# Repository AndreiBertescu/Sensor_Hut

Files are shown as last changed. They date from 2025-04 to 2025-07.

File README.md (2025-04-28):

# SensorHut V2

<p align="center"><br>
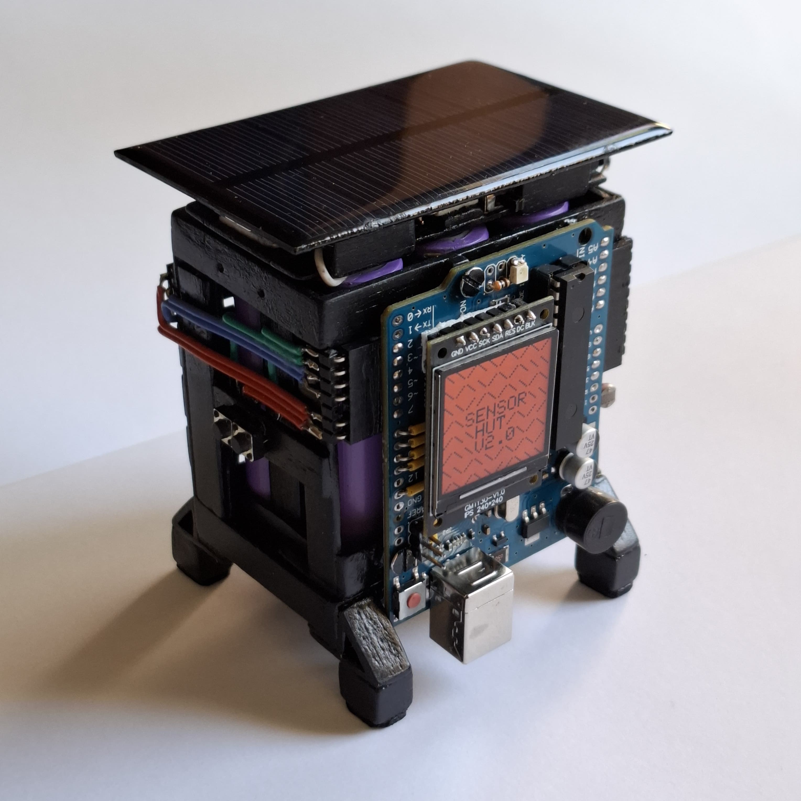
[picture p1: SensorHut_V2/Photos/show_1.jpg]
render
  
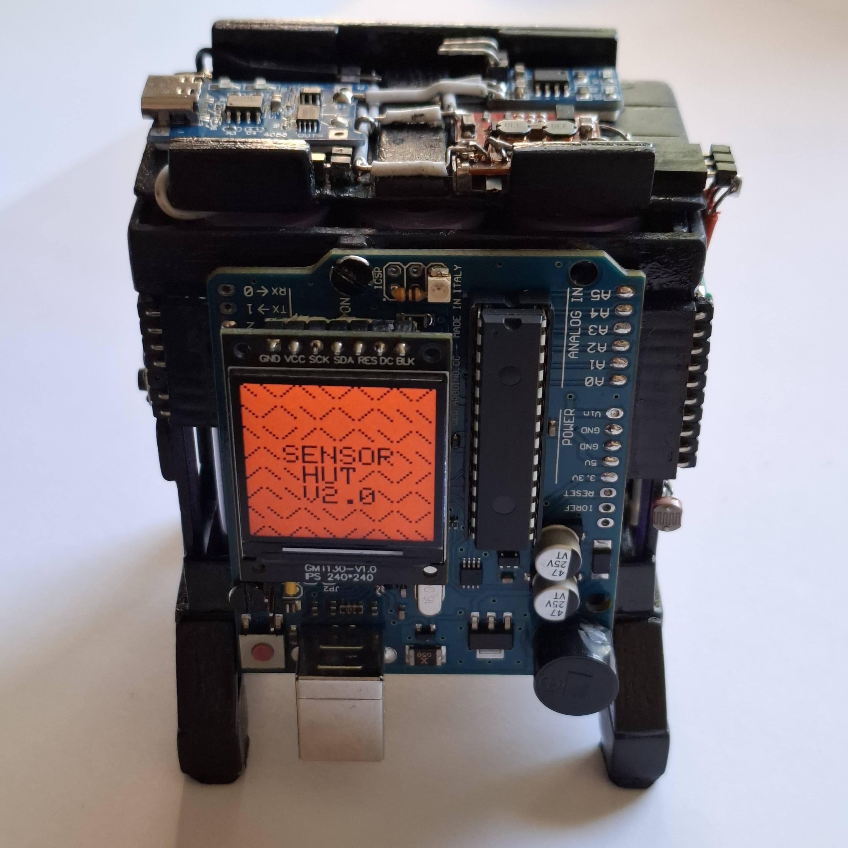
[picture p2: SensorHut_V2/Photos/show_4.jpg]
  
</p>

## Description
- The SensorHut is an Arduino-powered sensor array that can measure temperature, humidity, barometric pressure, light level, along with time-keeping and battery voltage measurement. It has a 2.4" LCD display that shows all this data, two push buttons, and a 6-cell rechargeable battery pack that can keep it powered for up to 2 weeks.

### Features
- **All the sensors are removable**, along with the battery pack, Arduino, and power circuit, allowing for easy maintenance, replacement, or reuse of components.
- It is powered by six 2200mAh LiPo batteries that can be recharged through USB-C or an attachable solar panel.
- The power consumption is 145mW while in sleep mode and 925mW while the screen is lit. Given the battery capacity and assuming no solar charging, the device should last about 15 days.
- It features two push buttons:
  - The first button refreshes sensor data and turns on the display for the programmed 16 seconds.
  - The second button toggles **power-saving mode**, which disables the LED, buzzer, and display backlight for a longer duration (10 minutes for power-saving mode, 1 minute for standard mode).
- The main Arduino board has been heavily modified to decrease power consumption and ease assembly:
  - All female pin sockets were removed and reattached on the underside of the board.
  - Since the required 5V is generated with an external step-up converter, the 12V power connector was replaced with a buzzer.
  - An LED and the 1.3" LCD display were wired and attached directly to the Arduino board, reducing the number of placed components and making them visible.
  - Always-on and auxiliary LEDs were removed.
  - The power pins on the ATMEGA16U2 auxiliary IC, along with the RX and TX LEDs, were rewired to be active only when the board is connected via the USB-B port ([tutorial](https://www.defproc.co.uk/tutorial/how-to-reduce-arduino-uno-power-usage-by-95/)).

<p align="center"><br>
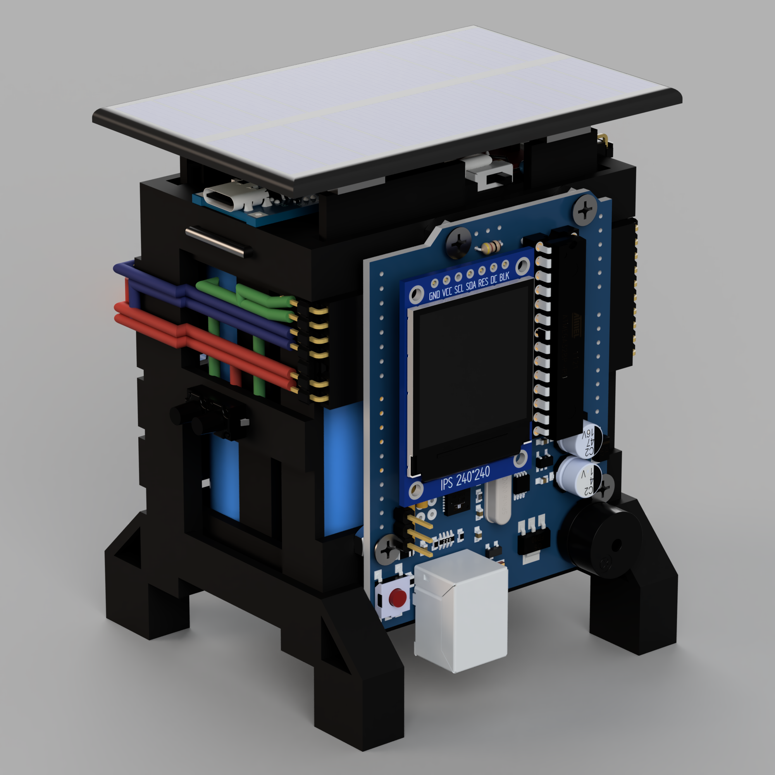
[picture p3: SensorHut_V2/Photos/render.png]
  
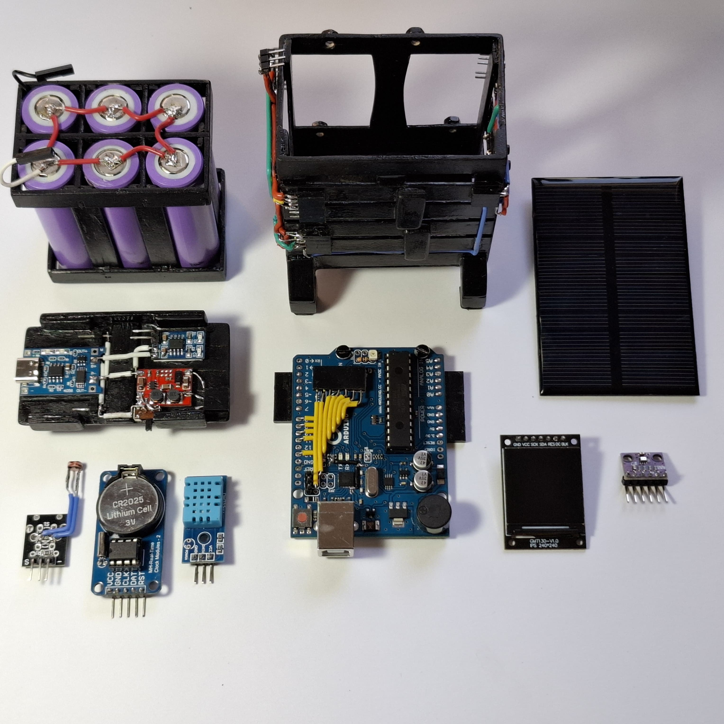
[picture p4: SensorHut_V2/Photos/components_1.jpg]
  
  <br>
  gif
</p>

## Improvements Added in Version 2
- Version 2's frame was built from popsicle sticks attached with Loctite superglue, offering a much stronger structure compared to Version 1's 1mm steel wireframe.
- Five more batteries were added to greatly increase battery capacity.
- Greater attention was given to frame design. The whole SensorHut was designed in tandem in Fusion 360 to ensure proper sizing and simplify assembly.
- The Arduino board is now much more visible and plays a bigger role in the overall aesthetics of the SensorHut.
- The power delivery circuits were removed from the solar panel and placed on a dedicated frame on top of the hut.
- The SensorHut can now function entirely without the solar panel (in Version 1, the solar charging was very weak).
- The wire harness was greatly simplified from the previous "spiderweb" mess. Wires are now routed neatly along the left and right sides of the hut and can easily be removed by detaching the right-angle pin headers from the Arduino sockets.

## Bill of Materials
- Arduino Uno Rev3 - [www.arduino.cc](https://store.arduino.cc/en-ro/products/arduino-uno-rev3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)
- DHT11 module - [www.optimusdigital.ro](https://www.optimusdigital.ro/en/temperature-sensors/4762-modul-senzor-de-temperatura-dht11-cu-led.html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)
- BMP280 module - [www.optimusdigital.ro](https://www.optimusdigital.ro/en/pressure-sensors/12417-modul-senzor-de-presiune-barometric-bmp280.html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)
- KY-018 module - [www.optimusdigital.ro](https://www.optimusdigital.ro/en/optical-sensors/13060-photosensitive-resistor-sensor-module-for-arduino.html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)
- DS1302 module - [www.optimusdigital.ro](https://www.optimusdigital.ro/en/all-products/12988-ds1302-real-time-clock-module-no-battery.html)
- ST7789 TFT LCD - [www.aliexpress.com](https://www.aliexpress.com/item/1005008175467166.html)
- 2x push buttons - [www.optimusdigital.ro](https://www.optimusdigital.ro/en/buttons-and-switches/1119-6x6x6-push-button.html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)
- Passive buzzer - [www.optimusdigital.ro](https://www.optimusdigital.ro/en/buzzers/634-5v-passive-buzzer.html?search_query=buzzer&results=87)
- Single-strand wires - [www.optimusdigital.ro](https://www.optimusdigital.ro/en/kits/11951-plusivo-pvc-insulated-wire-kit-20awg-6-colors-7m-each.html)
- 5.5V 120mA polycrystalline solar cell - [www.aliexpress.com](https://www.aliexpress.com/item/1005007402518746.html)
- 1A 5V for 3.7V solar controller - [www.aliexpress.com](https://www.aliexpress.com/item/1005003063466363.html)
- 2.5–15V to 5V step-up voltage regulator - [www.aliexpress.com](https://www.aliexpress.com/item/1005005911490910.html)
- 5V 1A USB-C lithium battery charger - [www.aliexpress.com](https://www.aliexpress.com/item/1005003598600322.html)
- 6x 3.7V 2200mAh rechargeable batteries - [www.aliexpress.com](https://www.aliexpress.com/item/1005001265547747.html)
- 2.54mm pitch pin headers and sockets of various lengths - [www.optimusdigital.ro](https://www.optimusdigital.ro/en/kits/4737-connector-assortment-kit-1004-pcs.html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)
- 1MΩ resistor
- 330Ω resistor
- Green SMD LED
- SPDT switch
- 30x1mm steel wires (for 2x clamps)
- Popsicle sticks (for the frame)

## Version 1 Schematic
(Note: Version 2 has a different pinout.)
Schematic1

## Version 1 Images
Bare frame with all detachable components removed

<p align="center">
  Bare Frame 1
  Bare Frame 2
</p>

Components

<p align="center">
  Components 1
  Components 2
</p>

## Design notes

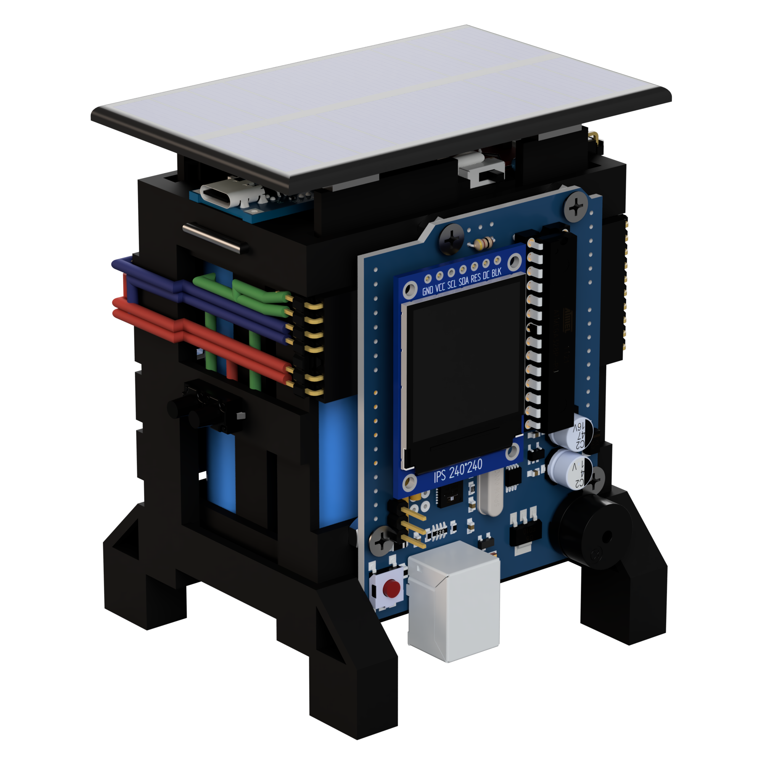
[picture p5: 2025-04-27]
SensorHut_V2/Photos/render_no_background.png

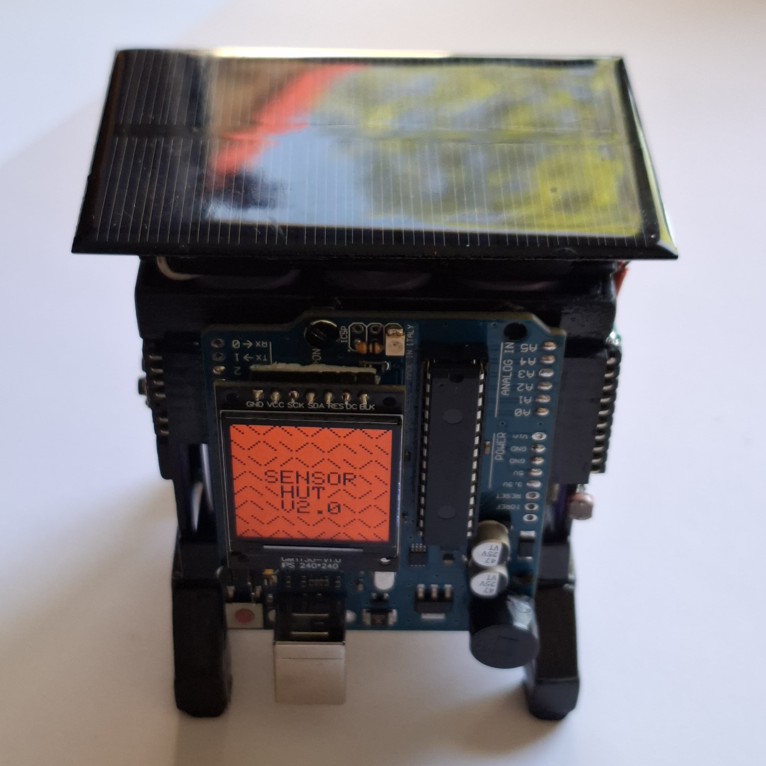
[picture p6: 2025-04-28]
SensorHut_V2/Photos/show_3.jpg

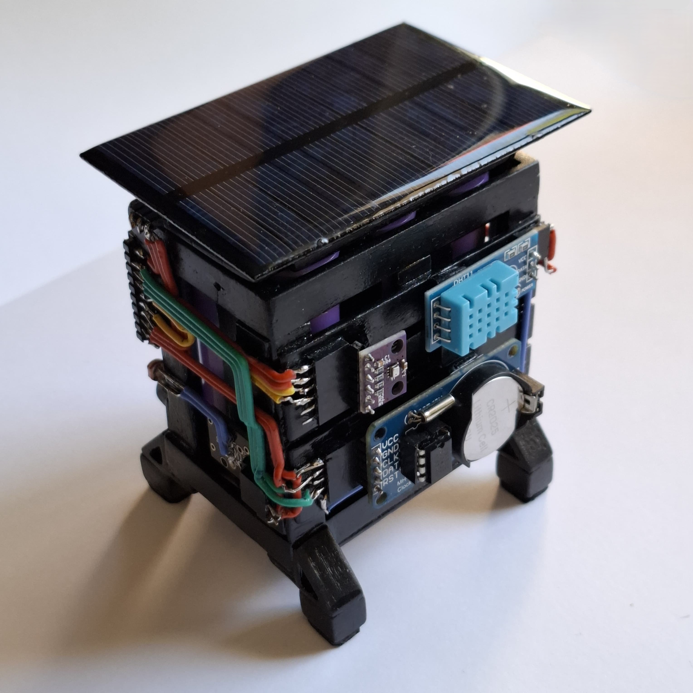
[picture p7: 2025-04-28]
SensorHut_V2/Photos/show_2.jpg

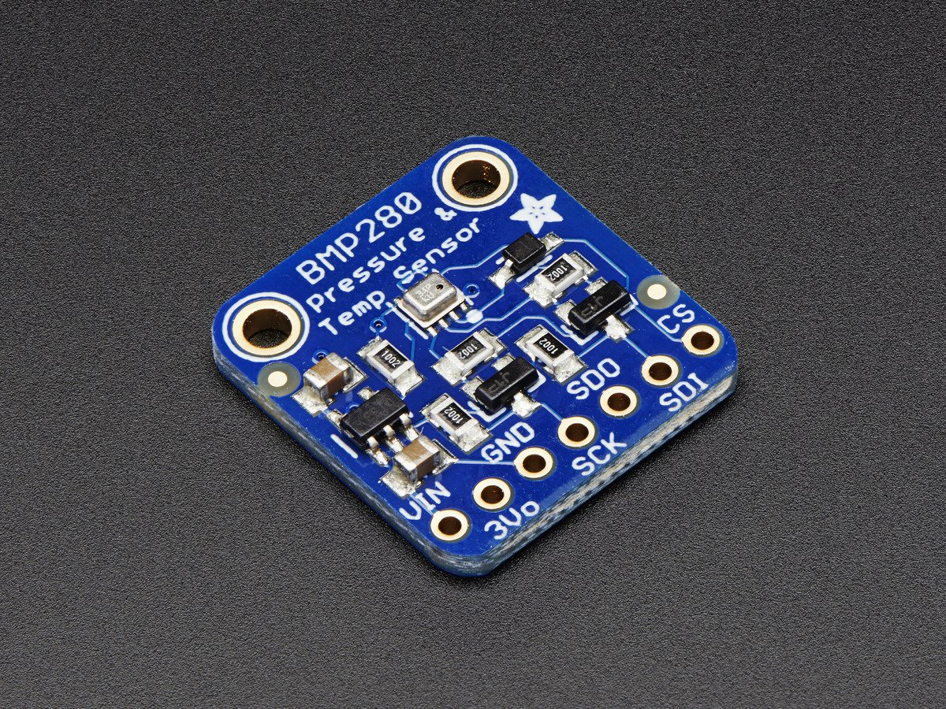
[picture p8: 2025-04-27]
SensorHut_V2/src/bmp280/assets/board.jpg

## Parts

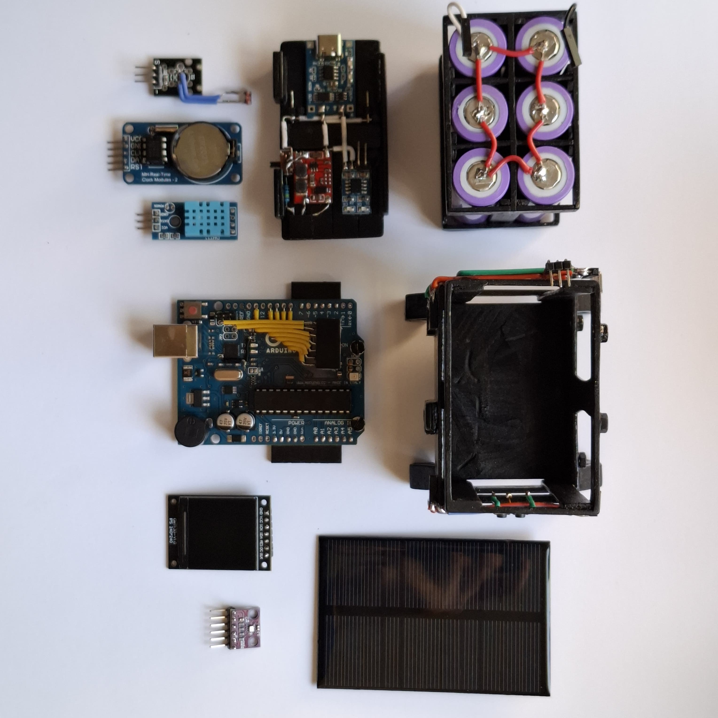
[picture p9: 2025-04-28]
SensorHut_V2/Photos/components_2.jpg

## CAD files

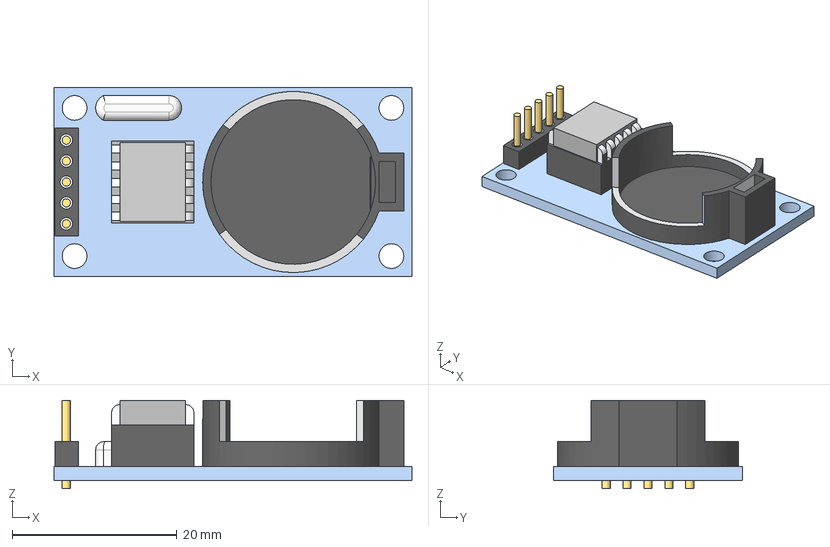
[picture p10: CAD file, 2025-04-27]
SensorHut_V2/3D models/Used parts/DS1302.stp
43.5 x 23.0 x 10.7 mm

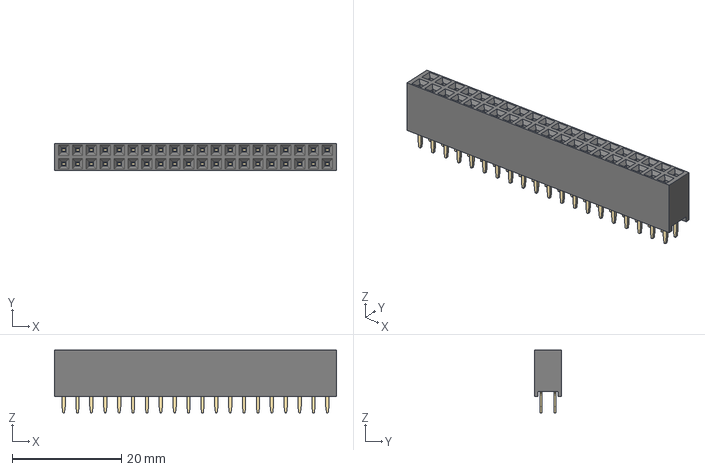
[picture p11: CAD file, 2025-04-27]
SensorHut_V2/3D models/Used parts/Header connectors/female/DS1023-2x20SF11.stp
51.6 x 5.00 x 11.5 mm

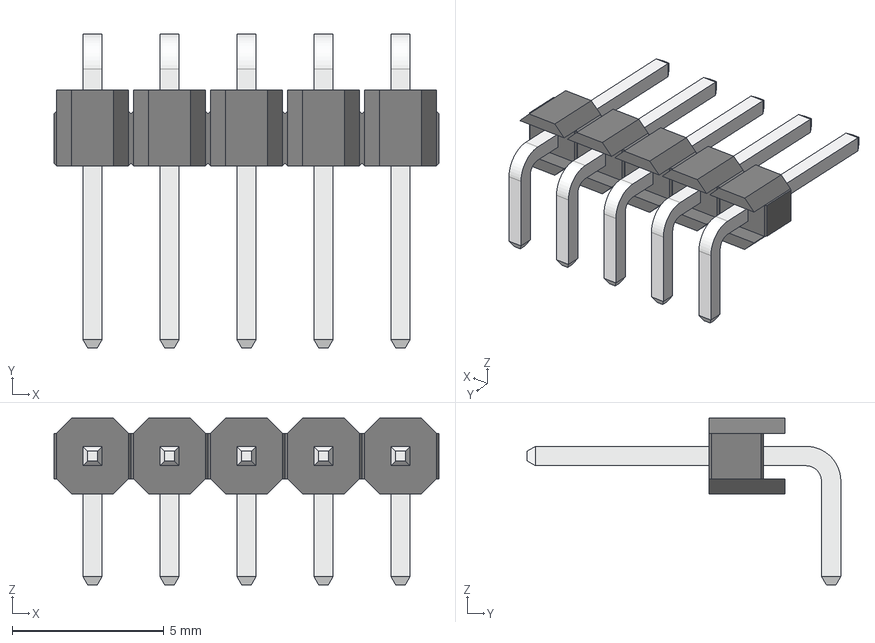
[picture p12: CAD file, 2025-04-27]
SensorHut_V2/3D models/Used parts/Header connectors/right_angle/2.54mm/DS1022-1x5RD61.stp
12.7 x 10.4 x 5.50 mm

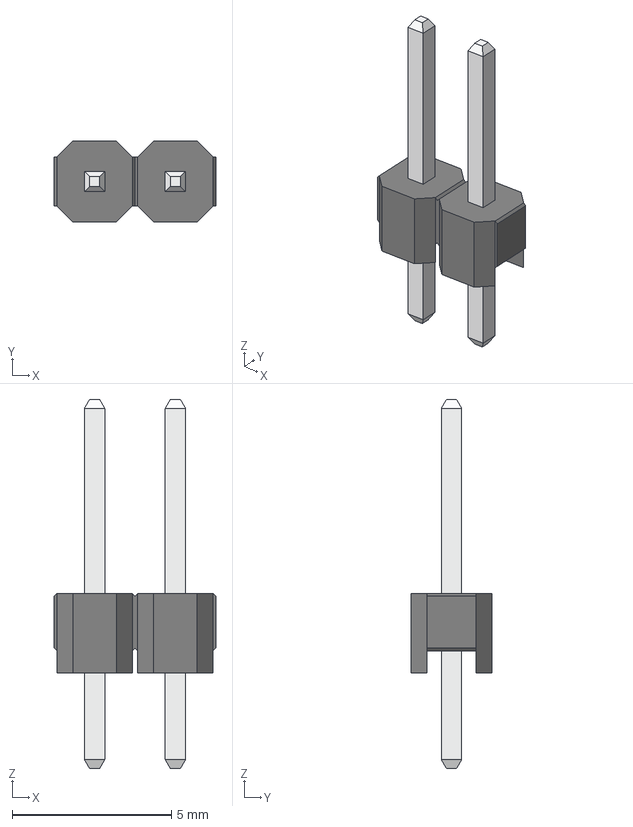
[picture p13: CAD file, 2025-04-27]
SensorHut_V2/3D models/Used parts/Header connectors/vertical/2.54mm/DS1021-1x2S61.stp
5.08 x 2.54 x 11.6 mm

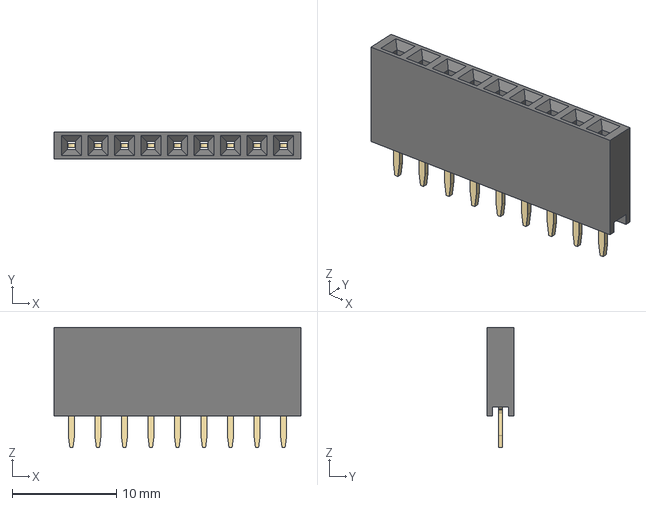
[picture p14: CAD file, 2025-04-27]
SensorHut_V2/3D models/Used parts/Header connectors/female/DS1023-1x9SF11.stp
23.7 x 2.54 x 11.5 mm

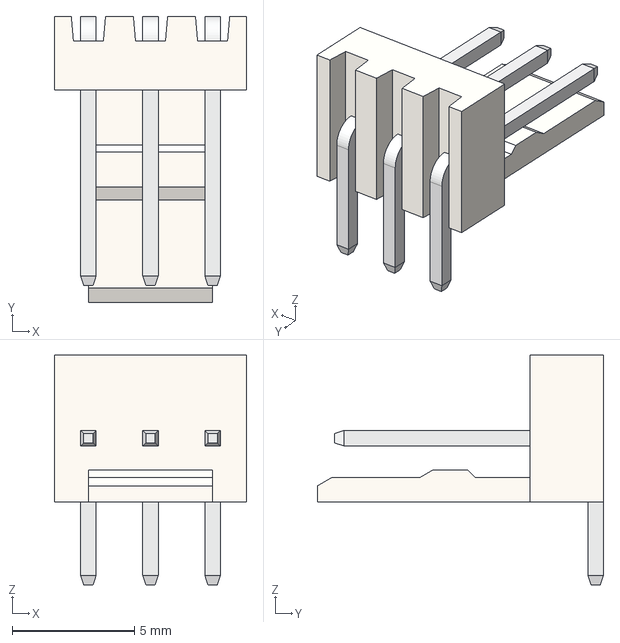
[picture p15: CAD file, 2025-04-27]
SensorHut_V2/3D models/Used parts/Header connectors/right_angle/2.54mm/DS1070-3MRV6B.stp
7.87 x 11.7 x 9.40 mm

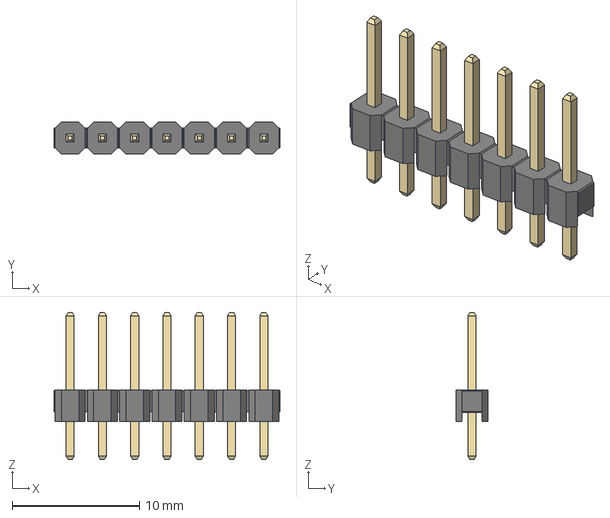
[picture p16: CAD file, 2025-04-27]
SensorHut_V2/3D models/Used parts/Header connectors/vertical/2.54mm/DS1021-1x7SF11.stp
17.8 x 2.54 x 11.6 mm

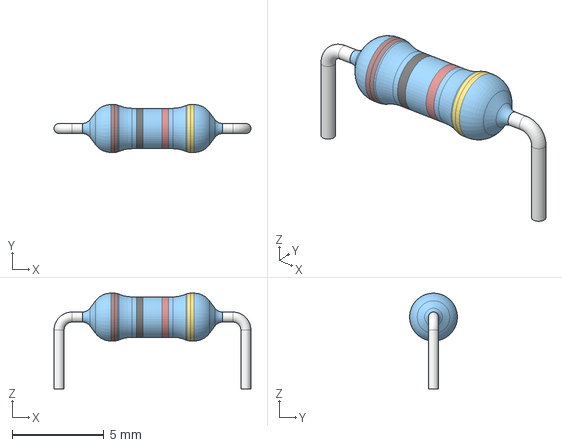
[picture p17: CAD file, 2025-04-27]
SensorHut_V2/3D models/Used parts/RES-0.25W-H-MF.stp
10.7 x 2.60 x 5.20 mm

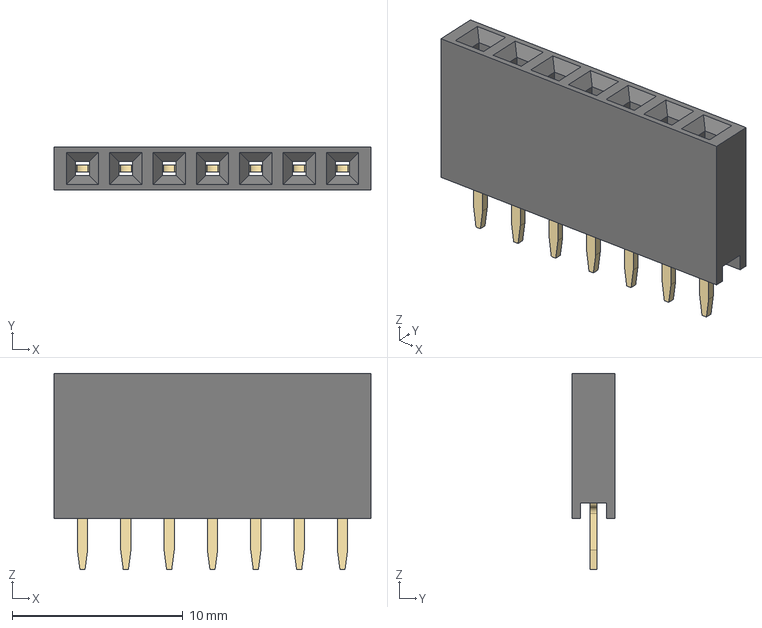
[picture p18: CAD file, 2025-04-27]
SensorHut_V2/3D models/Used parts/Header connectors/female/DS1023-1x7SF11.stp
18.6 x 2.54 x 11.5 mm

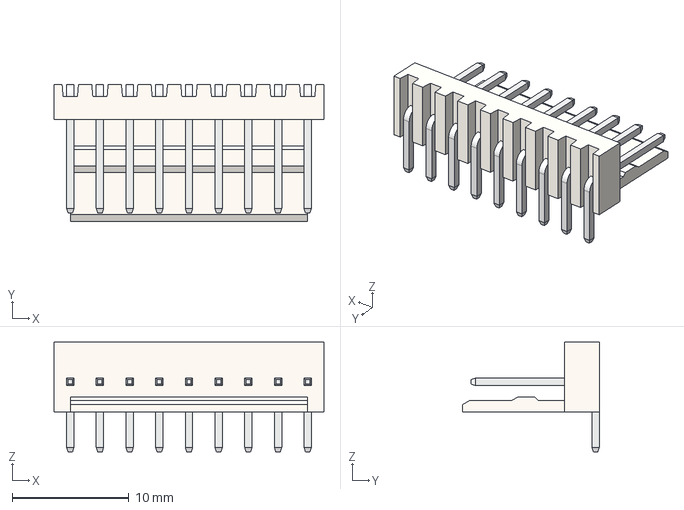
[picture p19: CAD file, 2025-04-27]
SensorHut_V2/3D models/Used parts/Header connectors/right_angle/2.54mm/DS1070-9MRV6B.stp
23.1 x 11.7 x 9.40 mm

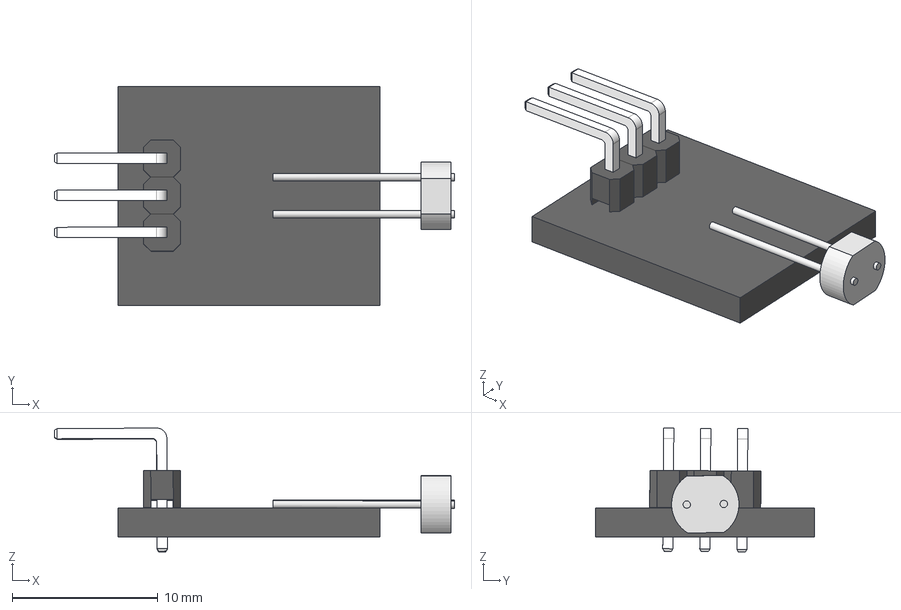
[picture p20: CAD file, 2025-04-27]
SensorHut_V2/3D models/Used parts/Photoresistor.stp
27.4 x 15.0 x 8.49 mm
board
User Library-PLS-3R
User Library-Photoresistor

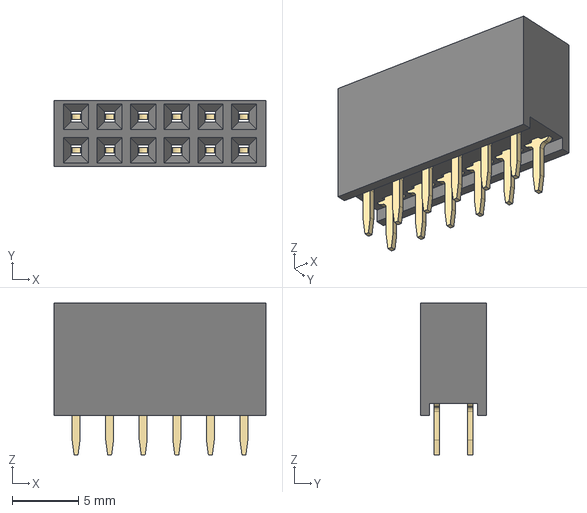
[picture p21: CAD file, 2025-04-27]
SensorHut_V2/3D models/Used parts/Header connectors/female/DS1023-2x6SF11.stp
16.0 x 5.00 x 11.5 mm

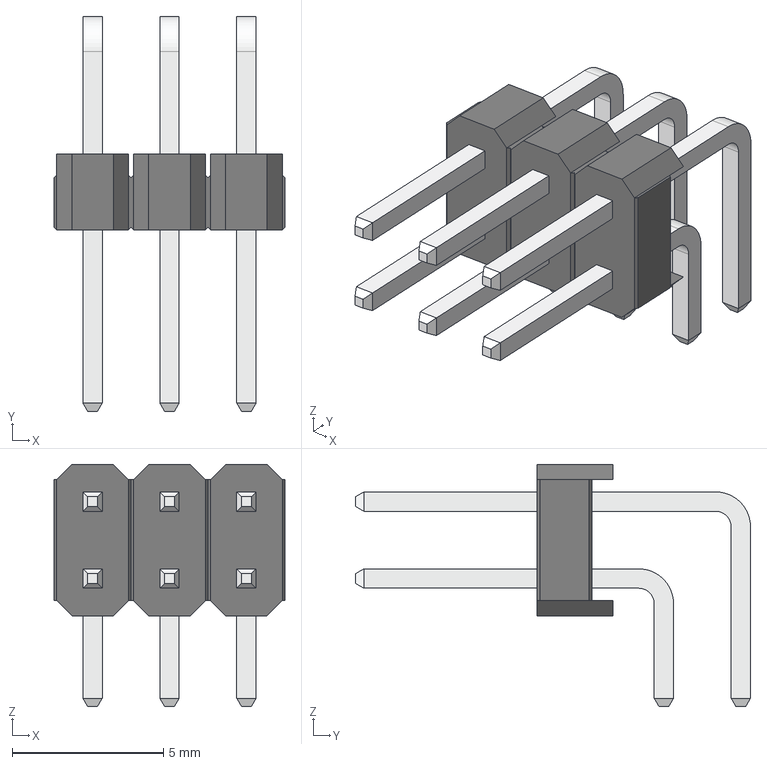
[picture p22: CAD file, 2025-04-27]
SensorHut_V2/3D models/Used parts/Header connectors/right_angle/2.54mm/DS1022-2x3R61.stp
7.62 x 13.0 x 8.00 mm

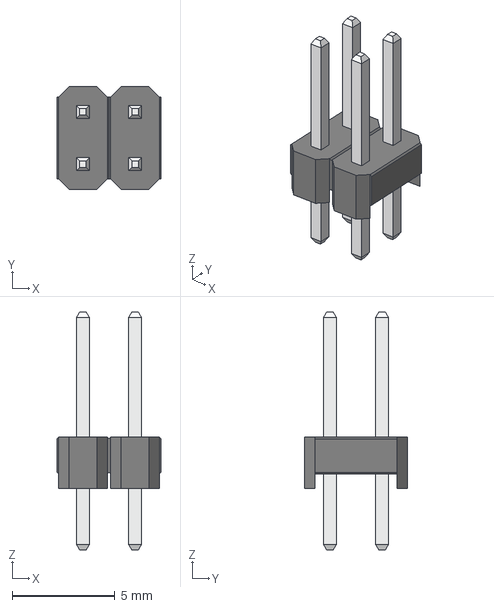
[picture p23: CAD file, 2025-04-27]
SensorHut_V2/3D models/Used parts/Header connectors/vertical/2.54mm/DS1021-2x2S61.stp
5.08 x 5.00 x 11.6 mm

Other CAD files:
SensorHut_V2/3D models/Used parts/Header connectors/vertical/2.54mm/DS1021-1x7S61.stp
SensorHut_V2/3D models/Used parts/OKY3501-5 Voltage Regulator.step
SensorHut_V2/3D models/Used parts/DHT11.step
SensorHut_V2/3D models/Used parts/Header connectors/female/DS1023-2x4SF11.stp
SensorHut_V2/3D models/Used parts/18650 Cell.stp
SensorHut_V2/3D models/Used parts/BMP280.stp
SensorHut_V2/3D models/Used parts/Buzzer.stp
SensorHut_V2/3D models/Used parts/Header connectors/female/DS1023-1x10SF11.stp
SensorHut_V2/3D models/Used parts/Header connectors/female/DS1023-1x1SF11.stp
SensorHut_V2/3D models/Used parts/Header connectors/female/DS1023-1x2SF11.stp
SensorHut_V2/3D models/Used parts/Header connectors/female/DS1023-1x3SF11.stp
SensorHut_V2/3D models/Used parts/Header connectors/female/DS1023-1x4SF11.stp
SensorHut_V2/3D models/Used parts/Header connectors/female/DS1023-1x5SF11.stp
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

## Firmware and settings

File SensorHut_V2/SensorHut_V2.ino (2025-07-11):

#include "src/dht11/dht11.h"
#include "src/ds1302/DS1302.h"
#include "src/bmp280/Adafruit_BMP280.h"
#include "src/st7789/Adafruit_ST7789.h"
#include <avr/sleep.h>
#include <avr/power.h>

#define ENABLE_SERIAL false
#define TIME_ALIVE 16000            // Rounds up to multiples of 4000
#define TIME_SHORT_SLEEP 60000 * 10 // Rounds up to multiples of 4000
#define TIME_LONG_SLEEP 60000 * 10  // Rounds up to multiples of 4000

#define DHT_PIN 4
#define LIGHT_SNSR_PIN A0  // Must be analog pin
#define BUZZER_PIN 6       // Must be 6 to use Timer #0 - HW constraint
#define BTN_1 2
#define BTN_2 3
#define LED_PIN 7          // HW constraint
#define RTC_RST_PIN 5      // Shouldn't be analog ???
#define RTC_DATA_PIN A2
#define RTC_SCKL_PIN A1
#define BMP280_SDA_PIN A4  // Must be sda pin
#define BMP280_SCL_PIN A5  // Must be scl pin
#define LCD_DC 9           // HW constraint
#define LCD_RST 10         // HW constraint
#define LCD_BRT 8          // HW constraint
#define LCD_SCK 13         // Must be sck pin - HW constraint
#define LCD_MOSI 11        // Must be mosi pin - HW constraint
#define BATT_SNSR_PIN A3   // Must be analog pin

// DHT11 temperature and humidity sensor
dht11 dht_inst;
uint8_t dht_temp;
uint8_t dht_hum;

// Battery sensor
int batt_snsr_val;

// Photoresistor
uint16_t light_snsr_val;

// Button interrupt flags
volatile bool btn_1_pressed;
volatile bool btn_2_pressed;

// DS1302 real time clock
DS1302 ds1302_inst(RTC_RST_PIN, RTC_DATA_PIN, RTC_SCKL_PIN);
Time t(2099, 1, 1, 0, 0, 0, Time::kSunday);

// BMP280 temperature, pressure and altitude sensor
Adafruit_BMP280 bmp;
int bmp_status;
int bmp_temp;
int bmp_press;
int bmp_altitude;

// ST7789 240x240 IPS display
Adafruit_ST7789 lcd = Adafruit_ST7789(-1, LCD_DC, LCD_RST);

// Other
char buf[64];
int power_saving_mode = 0;

void setup() {
  // Pin initialization
  pinMode(LIGHT_SNSR_PIN, INPUT);
  pinMode(BATT_SNSR_PIN, INPUT);
  pinMode(BUZZER_PIN, OUTPUT);
  pinMode(LED_PIN, OUTPUT);
  pinMode(LCD_BRT, OUTPUT);
  pinMode(BTN_1, INPUT_PULLUP);
  pinMode(BTN_2, INPUT_PULLUP);
  attachInterrupt(digitalPinToInterrupt(BTN_1), button1ISR, FALLING);
  attachInterrupt(digitalPinToInterrupt(BTN_2), button2ISR, FALLING);
  
  ACSR |= (1 << ACD);      // Disable analog comparator
  ADCSRA &= ~(1 << ADEN);  // Disable ADC
  TCCR1A = 0; // Disable Timer1
  TCCR1B = 0;
  TIMSK1 = 0;
  TCCR2A = 0; // Disable Timer2
  TCCR2B = 0;
  TIMSK2 = 0;

  // DS1302 initialization
  ds1302_inst.writeProtect(true);
  ds1302_inst.halt(false);
  t = ds1302_inst.time();
  if (t.getUnixFromMacros(__DATE__, __TIME__) > t.getUnixTime()) {
    ds1302_inst.writeProtect(false);
    ds1302_inst.time(Time(__DATE__, __TIME__));
    ds1302_inst.writeProtect(true);
  }

  // BMP280 initialization
  bmp_status = bmp.begin(BMP280_ADDRESS_ALT, BMP280_CHIPID);
  if (bmp_status) {
    bmp.setSampling(Adafruit_BMP280::MODE_NORMAL,     /* Operating Mode. */
                    Adafruit_BMP280::SAMPLING_X2,     /* Temp. oversampling */
                    Adafruit_BMP280::SAMPLING_X2,     /* Pressure oversampling */
                    Adafruit_BMP280::FILTER_X16,      /* Filtering. */
                    Adafruit_BMP280::STANDBY_MS_500); /* Standby time. */
  }

  // LCD initialization
  pinMode(LCD_BRT, OUTPUT);
  digitalWrite(LCD_BRT, HIGH);
  lcd.init(240, 240, SPI_MODE2);
  lcd.setRotation(2);
  lcd.setTextWrap(false);

  if (ENABLE_SERIAL) {
    // Serial initialization
    Serial.begin(9600);
  } else {
    // Buzzer confirm end of setup
    startupRoutine();
  }
}

void loop() {
  if (ENABLE_SERIAL) {
    Serial.println();
  }

  if(power_saving_mode != 2 || (btn_1_pressed || btn_2_pressed))
    digitalWrite(LCD_BRT, HIGH);

  handleButtons();
  handleBATT_SNSR();
  handleLIGHT_SNSR();
  handleDHT();
  handleBMP280();
  handleDS1302();
  handleLCD();

  sleepFor(TIME_ALIVE);
  digitalWrite(LCD_BRT, LOW);
  digitalWrite(LED_PIN, LOW);

  sleepFor(power_saving_mode == 1 ? TIME_LONG_SLEEP : TIME_SHORT_SLEEP);  // ~11mA less power usage than delay function
  // delay(1000);
}

void handleButtons() {
  if (btn_1_pressed) {
    activateBuzzer(1);
    power_saving_mode = (power_saving_mode + 1) % 3;

    btn_1_pressed = false;
  }
  if (btn_2_pressed) {
    if (power_saving_mode == 0) {
      activateBuzzer(2);
    } else {
      delay(500);
    }

    btn_2_pressed = false;
  }

  if (power_saving_mode == 0) {
    digitalWrite(LED_PIN, HIGH);
  }
}

void handleBATT_SNSR() {
  int battery_voltage = 0;
  int nr_samples = 20;

  ADCSRA |= (1 << ADEN);  // Enable ADC
  for(int i=0; i<nr_samples; i++) {
    battery_voltage += analogRead(BATT_SNSR_PIN);
    delay(10);
  }
  batt_snsr_val = map(battery_voltage/nr_samples, 0, 1023, 0, 500);
  ADCSRA &= ~(1 << ADEN);  // Disable ADC

  if (ENABLE_SERIAL) {
    sprintf(buf, "Battery sensor: %u.%.2uV", batt_snsr_val / 100 % 10, batt_snsr_val % 100);
    Serial.println(buf);
  }
}

void handleLIGHT_SNSR() {
  ADCSRA |= (1 << ADEN);  // Enable ADC
  light_snsr_val = map(analogRead(LIGHT_SNSR_PIN), 1023, 0, 0, 100);
  ADCSRA &= ~(1 << ADEN);  // Disable ADC

  if (ENABLE_SERIAL) {
    sprintf(buf, "Light sensor: %u%%", light_snsr_val);
    Serial.println(buf);
  }
}

void handleDHT() {
  int status = dht_inst.read(DHT_PIN);

  if (status == 0) {
    dht_temp = dht_inst.temperature;
    dht_hum = dht_inst.humidity;
  }

  if (ENABLE_SERIAL) {
    sprintf(buf, "DHT11:%d - T: %uC - H: %u%%", status, dht_temp, dht_hum);
    Serial.println(buf);
  }
}

void handleBMP280() {
  if (bmp_status != BMP280_CHIPID) {
    bmp.setSampling(Adafruit_BMP280::MODE_NORMAL,  /* Operating Mode. */
                    Adafruit_BMP280::SAMPLING_X2,  /* Temp. oversampling */
                    Adafruit_BMP280::SAMPLING_X16, /* Pressure oversampling */
                    Adafruit_BMP280::FILTER_X16,   /* Filtering. */
                    Adafruit_BMP280::STANDBY_MS_500);
  }

  bmp_status = bmp.getId();

  if (bmp_status == BMP280_CHIPID) {
    bmp_temp = bmp.readTemperature();
    bmp_press = int(bmp.readPressure() / 100);
    bmp_altitude = bmp.readAltitude(1008);
  }

  if (ENABLE_SERIAL) {
    sprintf(buf, "BMP280:%u - T: %uC - P: %uhPa - A: %u", bmp_status, bmp_temp, bmp_press, bmp_altitude);
    Serial.println(buf);
  }
}

void handleDS1302() {
  t = ds1302_inst.time();

  if (ENABLE_SERIAL) {
    sprintf(buf, "RTC: %u/%u/%u - %u:%u:%u", t.date, t.mon, t.yr, t.hr, t.min, t.sec);
    Serial.println(buf);
  }
}

void handleLCD() {
  char str[20];
  int text_color = 0;

  lcd.setTextSize(2);
  if (power_saving_mode != 0) {
    text_color = (power_saving_mode == 1) ? ST77XX_RED : ST77XX_MAGENTA;
    lcd.fillScreen(ST77XX_BLACK);
  } else {
    if (light_snsr_val <= 50) {
      text_color = ST77XX_WHITE;
      lcd.fillScreen(ST77XX_BLACK);
    } else {
      text_color = ST77XX_BLACK;
      lcd.fillScreen(ST77XX_WHITE);
    }
  }
  lcd.setTextColor(text_color);

  // Battery
  lcd.setCursor(172, 10);
  if(batt_snsr_val < 320) {
    lcd.setTextColor(ST77XX_RED);
  } else if(batt_snsr_val < 370) {
    lcd.setTextColor(ST77XX_ORANGE);
  }
  sprintf(str, "%d.%.2dv", batt_snsr_val / 100 % 10, batt_snsr_val % 100);
  lcd.print(str);

  // Date
  lcd.setCursor(10, 10);
  if(t.yr <= 2000 || t.yr >= 2100) {
    sprintf(str, "RTC ERROR");
    lcd.setTextColor(ST77XX_ORANGE);
  } else {
    sprintf(str, "%02u/%02u/%04u", t.date, t.mon, t.yr);
    lcd.setTextColor(text_color);
  }
  lcd.print(str);
  lcd.setTextColor(text_color);

  // Time
  lcd.setTextSize(7);
  lcd.setCursor(17, 50);
  sprintf(str, "%02u:%02u", t.hr, t.min);
  lcd.print(str);

  // Temperature and Humidity
  lcd.setTextSize(3);
  lcd.setCursor(10, 130);
  sprintf(str, "T:%dC  H:%d%%", dht_temp, dht_hum);
  lcd.print(str);

  // Atmospheric pressure
  lcd.setCursor(10, 165);
  sprintf(str, "Pres: %dhPa", bmp_press);
  lcd.print(str);

  // Brightness
  lcd.setCursor(10, 200);
  sprintf(str, "Brgt: %u%%", light_snsr_val);
  lcd.print(str);

  // Power saving mode
  lcd.setTextSize(1);
  lcd.setCursor(205, 215);
  sprintf(str, "PS:%u", power_saving_mode);
  lcd.print(str);
}

// Helper functions and Interrupt routines
void startupRoutine() {
  // Splash screen
  const char* ascii_art[] = {
    "\\\\/\\\\/\\/\\/",
    "\\/\\\\/\\/\\\\\\",
    "\\\\//\\/\\\\/\\",
    "/\\SENSOR\\\\",
    "/\\\\HUT/\\//",
    "/\\\\V2.0\\/\\",
    "\\\\/\\\\/\\/\\/",
    "/\\/\\\\//\\\\\\",
    "\\/\\\\/\\/\\\\\\"
  };

  digitalWrite(LED_PIN, HIGH);
  lcd.fillScreen(ST77XX_RED);
  lcd.setTextColor(ST77XX_BLACK);
  lcd.setTextSize(4);
  lcd.setCursor(0,-5);
  for (int i = 0; i < sizeof(ascii_art) / sizeof(ascii_art[0]); i++) {
    lcd.println(ascii_art[i]);  // Print each line of the ASCII art
  }

  // Mii melody
  tone(6, 740); delay(108); // NOTE_FS5 (90% of 960/8 = 120ms -> 108ms), plus 12ms pause
  noTone(6); delay(120);    // REST (960 / 8)

  tone(6, 880); delay(108); // NOTE_A5
  noTone(6); delay(12);

  tone(6, 554); delay(108); // NOTE_CS5
  noTone(6); delay(120);    // REST

  tone(6, 880); delay(108); // NOTE_A5
  noTone(6); delay(120);    // REST

  tone(6, 740); delay(108); // NOTE_FS5
  noTone(6);

  tone(6, 587); delay(108); // NOTE_D5
  noTone(6);

  tone(6, 587); delay(108); // NOTE_D5
  noTone(6);

  tone(6, 587); delay(108); // NOTE_D5
  noTone(6);

  digitalWrite(LED_PIN, LOW);
  delay(500);
}

void button1ISR() {
  btn_1_pressed = true;
}

void button2ISR() {
  btn_2_pressed = true;
}

void activateBuzzer(uint8_t type) {
  switch (type) {
    case 1:
      tone(BUZZER_PIN, 500, 100);
      delay(110);
      tone(BUZZER_PIN, 800, 100);
      delay(110);
      tone(BUZZER_PIN, 1000, 100);
      delay(110);
      noTone(BUZZER_PIN);
      break;
    default:
      tone(BUZZER_PIN, 700, 100);
      delay(110);
      tone(BUZZER_PIN, 1000, 100);
      delay(110);
      noTone(BUZZER_PIN);
      break;
  }
}

// Watchdog ISR
ISR(WDT_vect) {}

// Setup Watchdog Timer for 8s sleep
void setupWatchdog() {
  MCUSR &= ~(1 << WDRF);  // Clear watchdog reset flag

  WDTCSR |= (1 << WDCE) | (1 << WDE);
  // WDTCSR = (1 << WDP3) | (1 << WDP0); // 8.0 seconds
  WDTCSR = (1 << WDP3);  // 4.0 seconds

  WDTCSR |= (1 << WDIE);  // Enable the WD interrupt (note no reset).
}

void sleepFor(unsigned long duration) {
  unsigned long slept = 0;

  setupWatchdog();
  set_sleep_mode(SLEEP_MODE_PWR_DOWN);
  sleep_enable();
  power_all_disable();  // Disables SPI, USART, TWI, Timers

  while (slept < duration && !btn_1_pressed && !btn_2_pressed) {

    sleep_cpu();
    slept += 4000;
  }

  power_all_enable();  // Enables SPI, USART, TWI, Timers
  sleep_disable();
}

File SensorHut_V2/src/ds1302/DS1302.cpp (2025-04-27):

#if defined(ARDUINO) && ARDUINO >= 100
#include "Arduino.h"
#else
#include "WProgram.h"
#endif
#include "DS1302.h"

#include <stdint.h>

namespace {

enum Register {
  kSecondReg       = 0,
  kMinuteReg       = 1,
  kHourReg         = 2,
  kDateReg         = 3,
  kMonthReg        = 4,
  kDayReg          = 5,
  kYearReg         = 6,
  kWriteProtectReg = 7,

  // The RAM register space follows the clock register space.
  kRamAddress0     = 32
};

enum Command {
  kClockBurstRead  = 0xBF,
  kClockBurstWrite = 0xBE,
  kRamBurstRead    = 0xFF,
  kRamBurstWrite   = 0xFE
};

// Establishes and terminates a three-wire SPI session.
class SPISession {
 public:
  SPISession(const int ce_pin, const int io_pin, const int sclk_pin)
      : ce_pin_(ce_pin), io_pin_(io_pin), sclk_pin_(sclk_pin) {
    digitalWrite(sclk_pin_, LOW);
    digitalWrite(ce_pin_, HIGH);
    delayMicroseconds(4);  // tCC
  }
  ~SPISession() {
    digitalWrite(ce_pin_, LOW);
    delayMicroseconds(4);  // tCWH
  }

 private:
  const int ce_pin_;
  const int io_pin_;
  const int sclk_pin_;
};

// Returns the decoded decimal value from a binary-coded decimal (BCD) byte.
// Assumes 'bcd' is coded with 4-bits per digit, with the tens place digit in
// the upper 4 MSBs.
uint8_t bcdToDec(const uint8_t bcd) {
  return (10 * ((bcd & 0xF0) >> 4) + (bcd & 0x0F));
}

// Returns the binary-coded decimal of 'dec'. Inverse of bcdToDec.
uint8_t decToBcd(const uint8_t dec) {
  const uint8_t tens = dec / 10;
  const uint8_t ones = dec % 10;
  return (tens << 4) | ones;
}

// Returns the hour in 24-hour format from the hour register value.
uint8_t hourFromRegisterValue(const uint8_t value) {
  uint8_t adj;
  if (value & 128)  // 12-hour mode
    adj = 12 * ((value & 32) >> 5);
  else           // 24-hour mode
    adj = 10 * ((value & (32 + 16)) >> 4);
  return (value & 15) + adj;
}

}  // namespace

Time::Time(const uint16_t yr, const uint8_t mon, const uint8_t date,
           const uint8_t hr, const uint8_t min, const uint8_t sec,
           const Day day) {
  this->yr   = yr;
  this->mon  = mon;
  this->date = date;
  this->hr   = hr;
  this->min  = min;
  this->sec  = sec;
  this->day  = day;
}

Time::Time(const char* DATE, const char* TIME) {
  // 1. Parse DATE
  char monthStr[4];
  sscanf(DATE, "%3s %hhu %hu", monthStr, &this->date, &this->yr);

  // 2. Convert month string to number
  const char* months = "JanFebMarAprMayJunJulAugSepOctNovDec";
  for (int i = 0; i < 12; i++) {
    if (strncmp(monthStr, months + i * 3, 3) == 0) {
      this->mon = i + 1;
      break;
    }
  }

  // 3. Parse TIME
  sscanf(TIME, "%hhu:%hhu:%hhu", &this->hr, &this->min, &this->sec);

  this->day = Time::kSunday; // default or placeholder
}

bool Time::isLeapYear(int year) {
  return (year % 4 == 0 && (year % 100 != 0 || year % 400 == 0));
}

unsigned long Time::daysSinceEpoch(int year, int month, int day) {
  // Days in each month (non-leap)
  const int daysInMonth[] = {31,28,31,30,31,30,31,31,30,31,30,31};
  unsigned long days = 0;

  for (int y = 1970; y < year; y++) {
    days += isLeapYear(y) ? 366 : 365;
  }

  for (int m = 1; m < month; m++) {
    if (m == 2 && isLeapYear(year))
      days += 29;
    else
      days += daysInMonth[m - 1];
  }

  days += (day - 1);
  return days;
}

unsigned long Time::getUnixFromMacros(const char* DATE, const char* TIME) {
  // Parse DATE → e.g., "Apr 18 2025"
  char monthStr[4];
  int day, year;
  sscanf(DATE, "%3s %d %d", monthStr, &day, &year);

  const char* months = "JanFebMarAprMayJunJulAugSepOctNovDec";
  int month = 0;
  for (int i = 0; i < 12; i++) {
    if (strncmp(monthStr, months + i * 3, 3) == 0) {
      month = i + 1;
      break;
    }
  }

  // Parse TIME → e.g., "13:45:27"
  int hour, min, sec;
  sscanf(TIME, "%d:%d:%d", &hour, &min, &sec);

  unsigned long days = daysSinceEpoch(year, month, day);
  return days * 86400UL + hour * 3600UL + min * 60UL + sec;
}

unsigned long Time::getUnixTime() {
	unsigned long days = daysSinceEpoch(this->yr, this->mon, this->date);
	return days * 86400UL + this->hr * 3600UL + this->min * 60UL + this->sec;
}

DS1302::DS1302(const uint8_t ce_pin, const uint8_t io_pin,
               const uint8_t sclk_pin) {
  ce_pin_ = ce_pin;
  io_pin_ = io_pin;
  sclk_pin_ = sclk_pin;

  digitalWrite(ce_pin, LOW);
  pinMode(ce_pin, OUTPUT);
  pinMode(io_pin, INPUT);
  digitalWrite(sclk_pin, LOW);
  pinMode(sclk_pin, OUTPUT);
}

void DS1302::writeOut(const uint8_t value, bool readAfter) {
  pinMode(io_pin_, OUTPUT);

  for (int i = 0; i < 8; ++i) {
    digitalWrite(io_pin_, (value >> i) & 1);
    delayMicroseconds(1);
    digitalWrite(sclk_pin_, HIGH);
    delayMicroseconds(1);

    if (readAfter && i == 7) {
      // We're about to read data -- ensure the pin is back in input mode
      // before the clock is lowered.
      pinMode(io_pin_, INPUT);
    } else {
      digitalWrite(sclk_pin_, LOW);
      delayMicroseconds(1);
    }
  }
}

uint8_t DS1302::readIn() {
  uint8_t input_value = 0;
  uint8_t bit = 0;
  pinMode(io_pin_, INPUT);

  // Bits from the DS1302 are output on the falling edge of the clock
  // cycle. This is called after readIn (which will leave the clock low) or
  // writeOut(..., true) (which will leave it high).
  for (int i = 0; i < 8; ++i) {
    digitalWrite(sclk_pin_, HIGH);
    delayMicroseconds(1);
    digitalWrite(sclk_pin_, LOW);
    delayMicroseconds(1);

    bit = digitalRead(io_pin_);
    input_value |= (bit << i);  // Bits are read LSB first.
  }

  return input_value;
}

uint8_t DS1302::readRegister(const uint8_t reg) {
  const SPISession s(ce_pin_, io_pin_, sclk_pin_);

  const uint8_t cmd_byte = (0x81 | (reg << 1));
  writeOut(cmd_byte, true);
  return readIn();
}

void DS1302::writeRegister(const uint8_t reg, const uint8_t value) {
  const SPISession s(ce_pin_, io_pin_, sclk_pin_);

  const uint8_t cmd_byte = (0x80 | (reg << 1));
  writeOut(cmd_byte);
  writeOut(value);
}

void DS1302::writeProtect(const bool enable) {
  writeRegister(kWriteProtectReg, (enable << 7));
}

void DS1302::halt(const bool enable) {
  uint8_t sec = readRegister(kSecondReg);
  sec &= ~(1 << 7);
  sec |= (enable << 7);
  writeRegister(kSecondReg, sec);
}

Time DS1302::time() {
  const SPISession s(ce_pin_, io_pin_, sclk_pin_);

  Time t(2099, 1, 1, 0, 0, 0, Time::kSunday);
  writeOut(kClockBurstRead, true);
  t.sec = bcdToDec(readIn() & 0x7F);
  t.min = bcdToDec(readIn());
  t.hr = hourFromRegisterValue(readIn());
  t.date = bcdToDec(readIn());
  t.mon = bcdToDec(readIn());
  t.day = static_cast<Time::Day>(bcdToDec(readIn()));
  t.yr = 2000 + bcdToDec(readIn());
  return t;
}
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

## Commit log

2024-03-16 Added buttons
2024-03-18 Added low power mode
2024-03-26 Added schematics
    [SensorHut.fzz]
2025-04-27 Added version 2
    [18650 Cell.stp, 4_PIN_PWM.stp, BMP280.stp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]
2025-04-28 Renamed some files and added photos
    [18650 Cell.stp, 4_PIN_PWM.stp, BMP280.stp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]
2025-05-01 Added some error mesages to the arduino project
    [SensorHut_V2.ino]
